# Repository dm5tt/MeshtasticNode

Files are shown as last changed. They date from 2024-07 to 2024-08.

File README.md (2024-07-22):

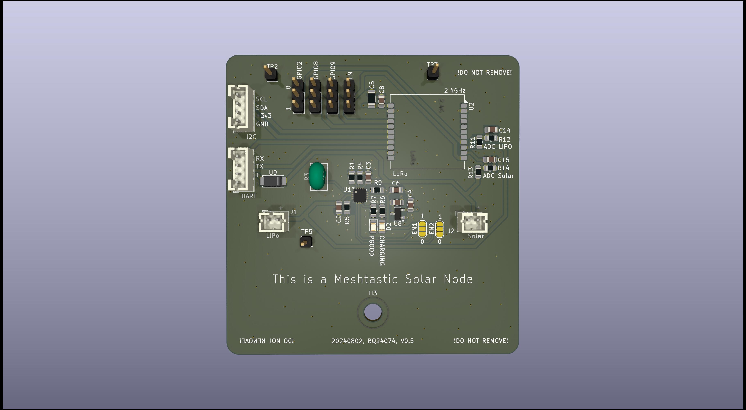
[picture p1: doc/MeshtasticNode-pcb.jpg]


## What is this thing?

This is a Heltec HT-CT62 based Meshtastic Router which can be integrated into a IP68 protected case.

Combined with a solar panel this device can be placed in remote areas to cover a wide range.

For power management a TI BQ24074 is being used which offers pseudo-MPPT and load switching (= battery being deactivated if the sun offers us enough energy to power the device alone).

Voltages can be measured via power divider to GPIO0 (VBUS) or GPIO1 (LiPo)

## Do I have to modify the Software?

No. Only some smaller changes regarding the pin mapping is required.

```
diff --git a/variants/heltec_esp32c3/pins_arduino.h b/variants/heltec_esp32c3/pins_arduino.h
index a717a370..b8ebc09c 100644
--- a/variants/heltec_esp32c3/pins_arduino.h
+++ b/variants/heltec_esp32c3/pins_arduino.h
@@ -6,8 +6,8 @@
 static const uint8_t TX = 21;
 static const uint8_t RX = 20;
 
-static const uint8_t SDA = 1;
-static const uint8_t SCL = 0;
+static const uint8_t SDA = 18;
+static const uint8_t SCL = 19;
 
 static const uint8_t SS = 8;
 static const uint8_t MOSI = 7;
diff --git a/variants/heltec_esp32c3/variant.h b/variants/heltec_esp32c3/variant.h
index 360d9bf1..4f66476d 100644
--- a/variants/heltec_esp32c3/variant.h
+++ b/variants/heltec_esp32c3/variant.h
@@ -1,16 +1,11 @@
-#define BUTTON_PIN 9

-#define LED_PIN 2 // LED
-#define LED_INVERTED 0

 #define HAS_SCREEN 0
 #define HAS_GPS 0
 #undef GPS_RX_PIN
 #undef GPS_TX_PIN
 
+#define BATTERY_PIN 1
+#define ADC_CHANNEL ADC1_GPIO1_CHANNEL
+
 #define USE_SX1262
 #define LORA_SCK 10
 #define LORA_MISO 6
```

### Box

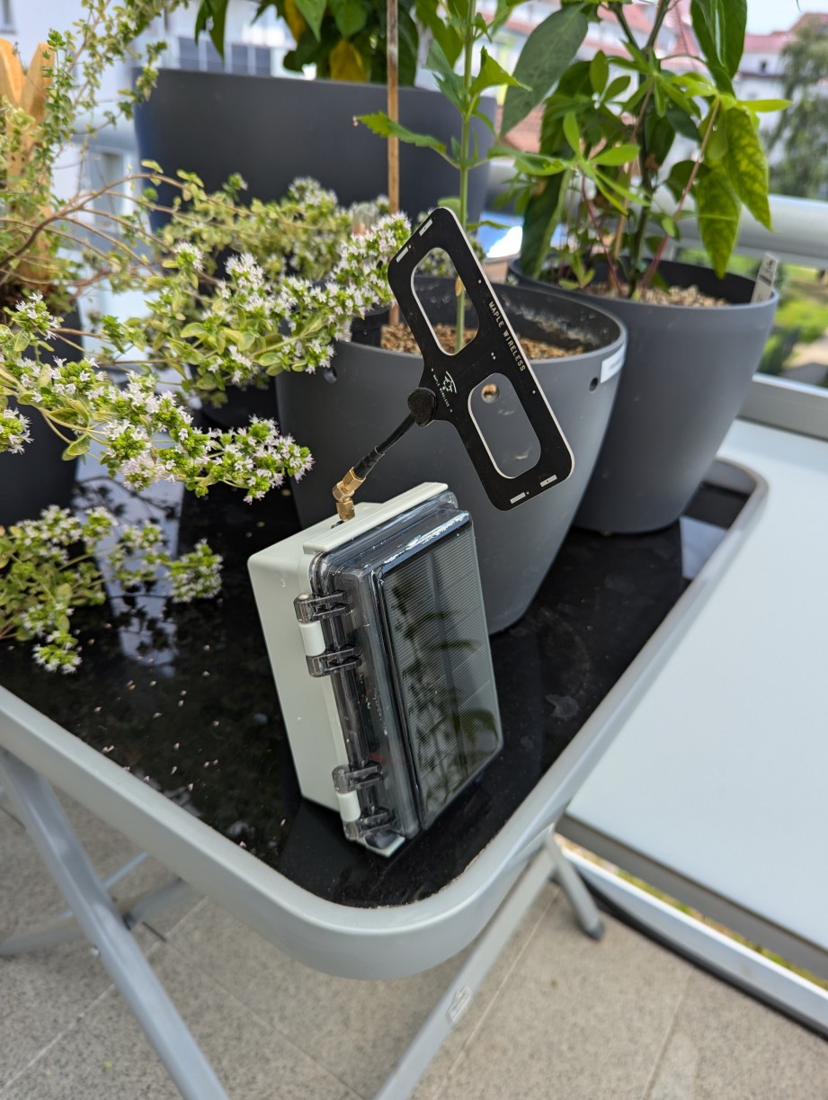
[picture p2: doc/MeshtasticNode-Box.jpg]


### Cabeling

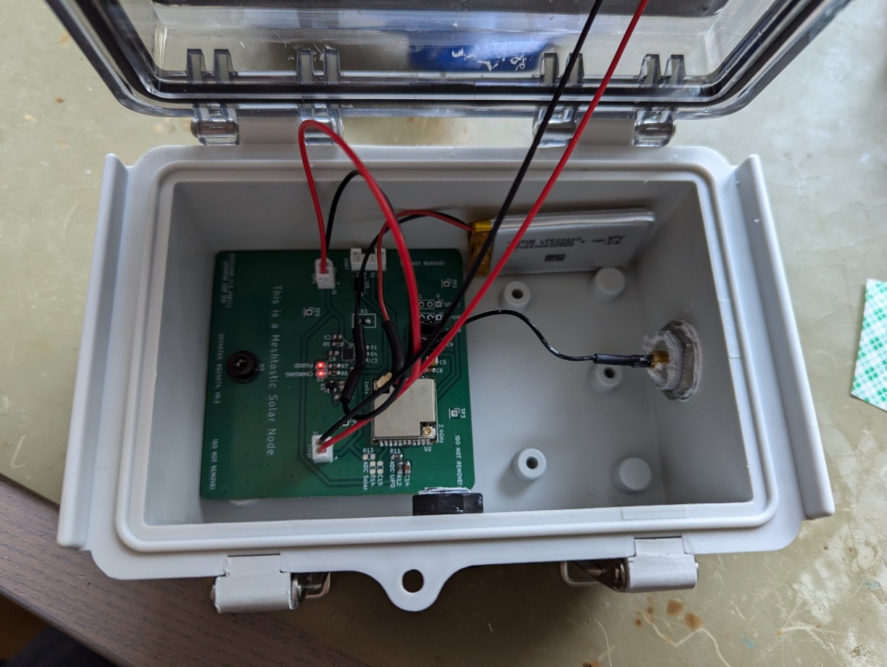
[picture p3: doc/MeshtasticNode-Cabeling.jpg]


### Flashing

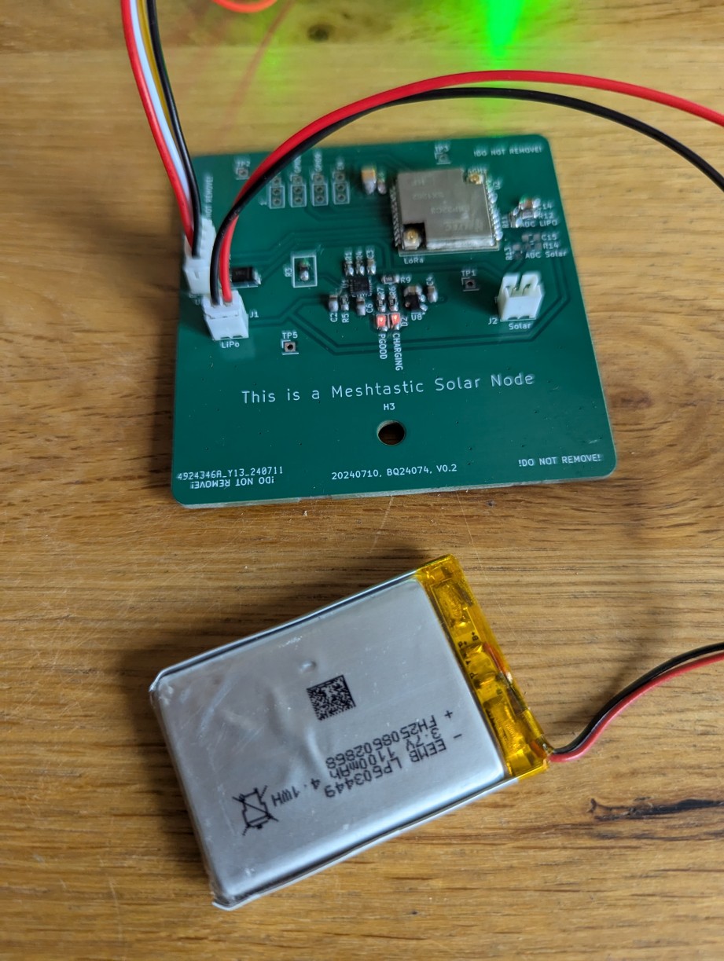
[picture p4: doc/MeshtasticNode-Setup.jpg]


## Lessons learned

Never ever use hot glue even when if the promise that it's UV resistant. It will fail and then the environment will kill all of your electronics.

Professional glue for construction work and water pools/boat seem to survive every kind of weather as long you keep it within its specs.

Using venting plugs with gore tex membrane.

## Future Changes

The solar charging IC will be replaced with    the new TI BQ25308 which will enable us to utilize solar panels from 4.5-17V without burning a single mA into heat.

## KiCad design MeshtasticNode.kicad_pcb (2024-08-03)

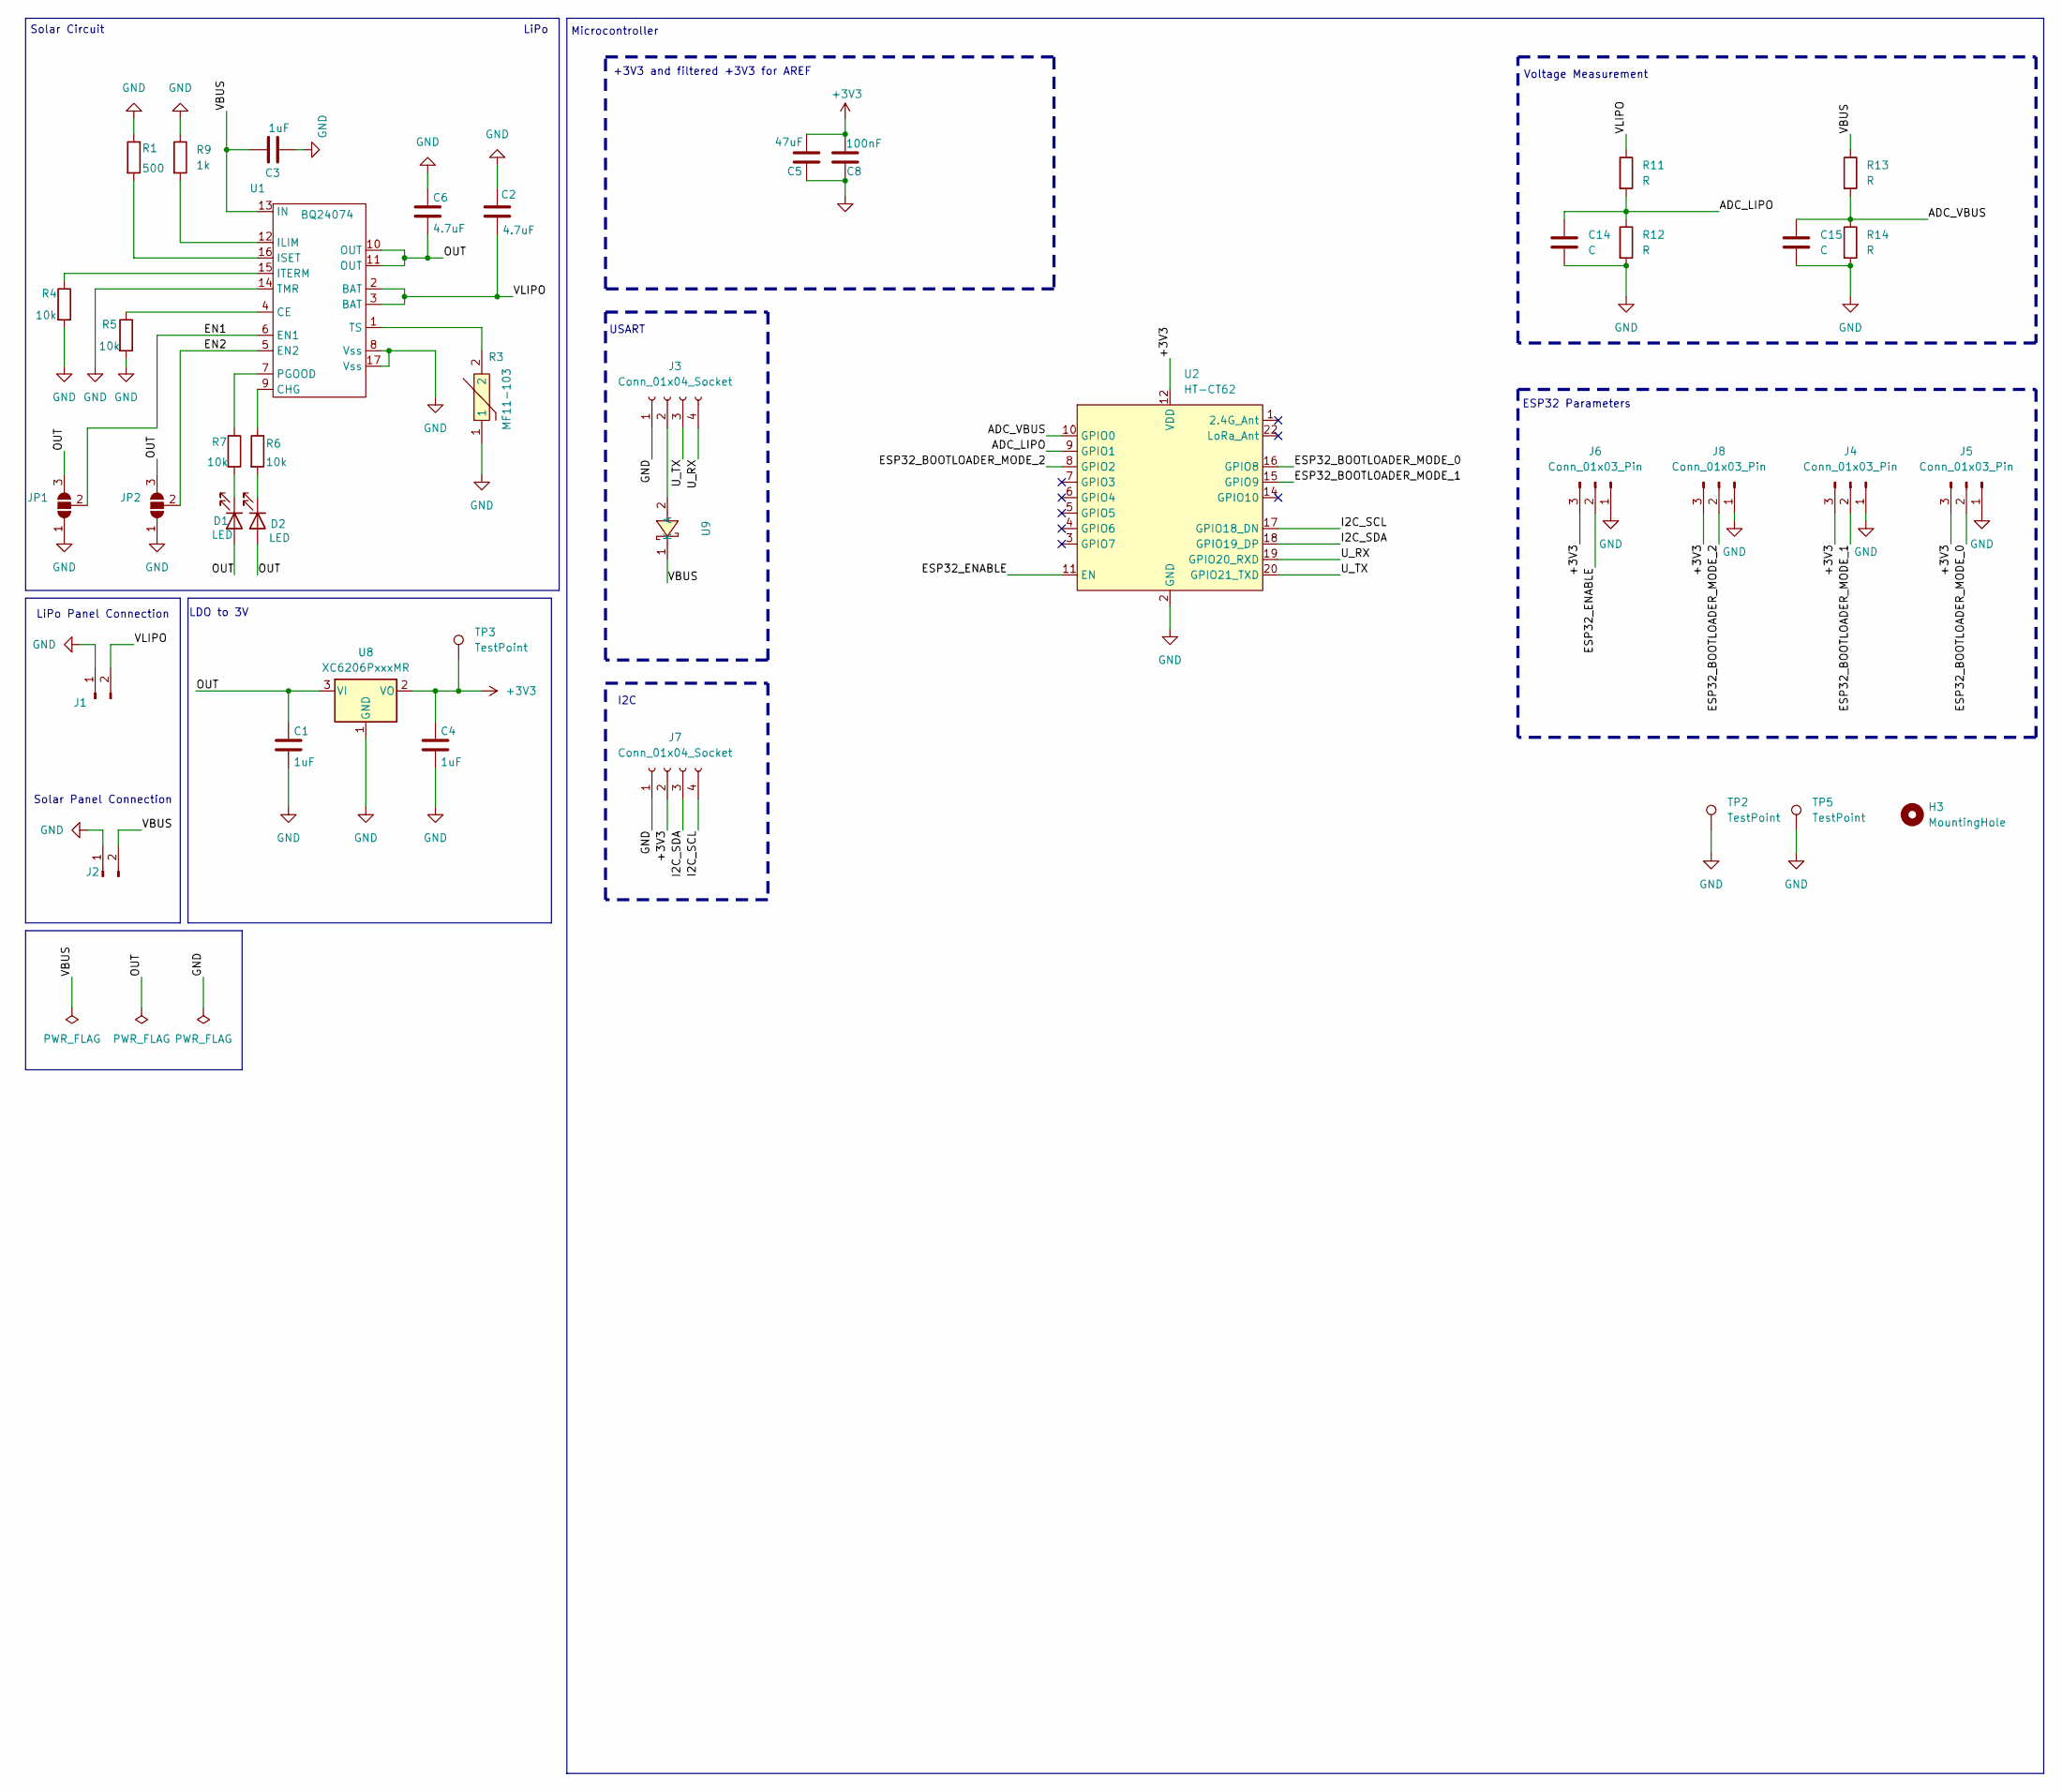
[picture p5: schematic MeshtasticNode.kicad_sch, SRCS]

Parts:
C1, C3, C4: 1uF; C_0805_2012Metric_Pad1.18x1.45mm_HandSolder
C2, C6: 4.7uF; C_0805_2012Metric_Pad1.18x1.45mm_HandSolder
C5: 47uF; R_1206_3216Metric_Pad1.30x1.75mm_HandSolder
C8: 100nF; C_0805_2012Metric_Pad1.18x1.45mm_HandSolder
C14, C15: C; C_0805_2012Metric_Pad1.18x1.45mm_HandSolder
D1, D2: LED; LED_0805_2012Metric_Pad1.15x1.40mm_HandSolder
H3: MountingHole; MountingHole_4.3mm_M4_DIN965
J1, J2: Conn_01x02_Socket; JST_PH_B2B-PH-K_1x02_P2.00mm_Vertical
J3, J7: Conn_01x04_Socket; JST_PH_B4B-PH-K_1x04_P2.00mm_Vertical
J4, J5, J6, J8: Conn_01x03_Pin; PinHeader_1x03_P2.54mm_Vertical
JP1, JP2: SolderJumper_3_Open; SolderJumper-3_P1.3mm_Open_RoundedPad1.0x1.5mm_NumberLabels
R1: 500; R_0805_2012Metric_Pad1.20x1.40mm_HandSolder
R3: MF11-103; RES-TH_L6.5-W4.0-P2.50-D0.5; LCSC Part C70913
R4, R5, R6, R7: 10k; R_0805_2012Metric_Pad1.20x1.40mm_HandSolder
R9: 1k; R_0805_2012Metric_Pad1.20x1.40mm_HandSolder
R11, R12, R13, R14: R; R_0805_2012Metric_Pad1.20x1.40mm_HandSolder
TP2, TP3, TP5: TestPoint; PinHeader_1x01_P2.54mm_Vertical
U1: BQ24074; VQFN-16-1EP_3x3mm_P0.5mm_EP1.68x1.68mm_ThermalVias
U2: HT-CT62; Heltec_HT-CT62
U8: XC6206PxxxMR; SOT-23-3
U9: SS26_C5350986; SMA_L4.3-W2.6-LS5.1-RD; LCSC Part C5350986

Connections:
+3V3: C4.1, C5.2, C8.2, J4.3, J5.3, J6.3, J7.2, J8.3, TP3.1, U2.12 (VDD), U8.2 (VO)
/ADC_LIPO: C14.1, R11.2, R12.1, U2.9 (GPIO1)
/ADC_VBUS: C15.1, R13.2, R14.1, U2.10 (GPIO0)
/EN1: JP1.2 (C), U1.6 (EN1)
/EN2: JP2.2 (C), U1.5 (EN2)
/ESP32_BOOTLOADER_MODE_0: J5.2, U2.16 (GPIO8)
/ESP32_BOOTLOADER_MODE_1: J4.2, U2.15 (GPIO9)
/ESP32_BOOTLOADER_MODE_2: J8.2, U2.8 (GPIO2)
/ESP32_ENABLE: J6.2, U2.11 (EN)
/I2C_SCL: J7.4, U2.17 (GPIO18_DN)
/I2C_SDA: J7.3, U2.18 (GPIO19_DP)
/OUT: C1.1, C6.2, D1.2 (A), D2.2 (A), JP1.3 (B), JP2.3 (B), U1.10 (OUT), U1.11 (OUT), U8.3 (VI)
/U_RX: J3.4, U2.19 (GPIO20_RXD)
/U_TX: J3.3, U2.20 (GPIO21_TXD)
/VBUS: C3.1, J2.2, R13.1, U1.13 (IN), U9.1 (K)
/VLIPO: C2.2, J1.2, R11.1, U1.2 (BAT), U1.3 (BAT)
GND: C1.2, C2.1, C3.2, C4.2, C5.1, C6.1, C8.1, C14.2, C15.2, J1.1, J2.1, J3.1, J4.1, J5.1, J6.1, J7.1, J8.1, JP1.1 (A), JP2.1 (A), R1.1, R3.1, R4.2, R5.2, R9.1, R12.2, R14.2, TP2.1, TP5.1, U1.8 (Vss), U1.14 (TMR), U1.17 (Vss), U2.2 (GND), U2.13 (GND), U2.21 (GND), U8.1 (GND)
unnamed: D1.1 (K), R7.2
unnamed: D2.1 (K), R6.2
unnamed: J3.2, U9.2 (A)
unnamed: R5.1, U1.4 (CE)
unnamed: R6.1, U1.9 (CHG)
unnamed: R9.2, U1.12 (ILIM)
unnamed: R1.2, U1.16 (ISET)
unnamed: R4.1, U1.15 (ITERM)
unnamed: R7.1, U1.7 (PGOOD)
unnamed: R3.2, U1.1 (TS)

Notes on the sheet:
ESP32 Parameters
Solar Circuit
Microcontroller
USART
Voltage Measurement
LiPo
LiPo Panel Connection
+3V3 and filtered +3V3 for AREF
Solar Panel Connection
LDO to 3V
I2C

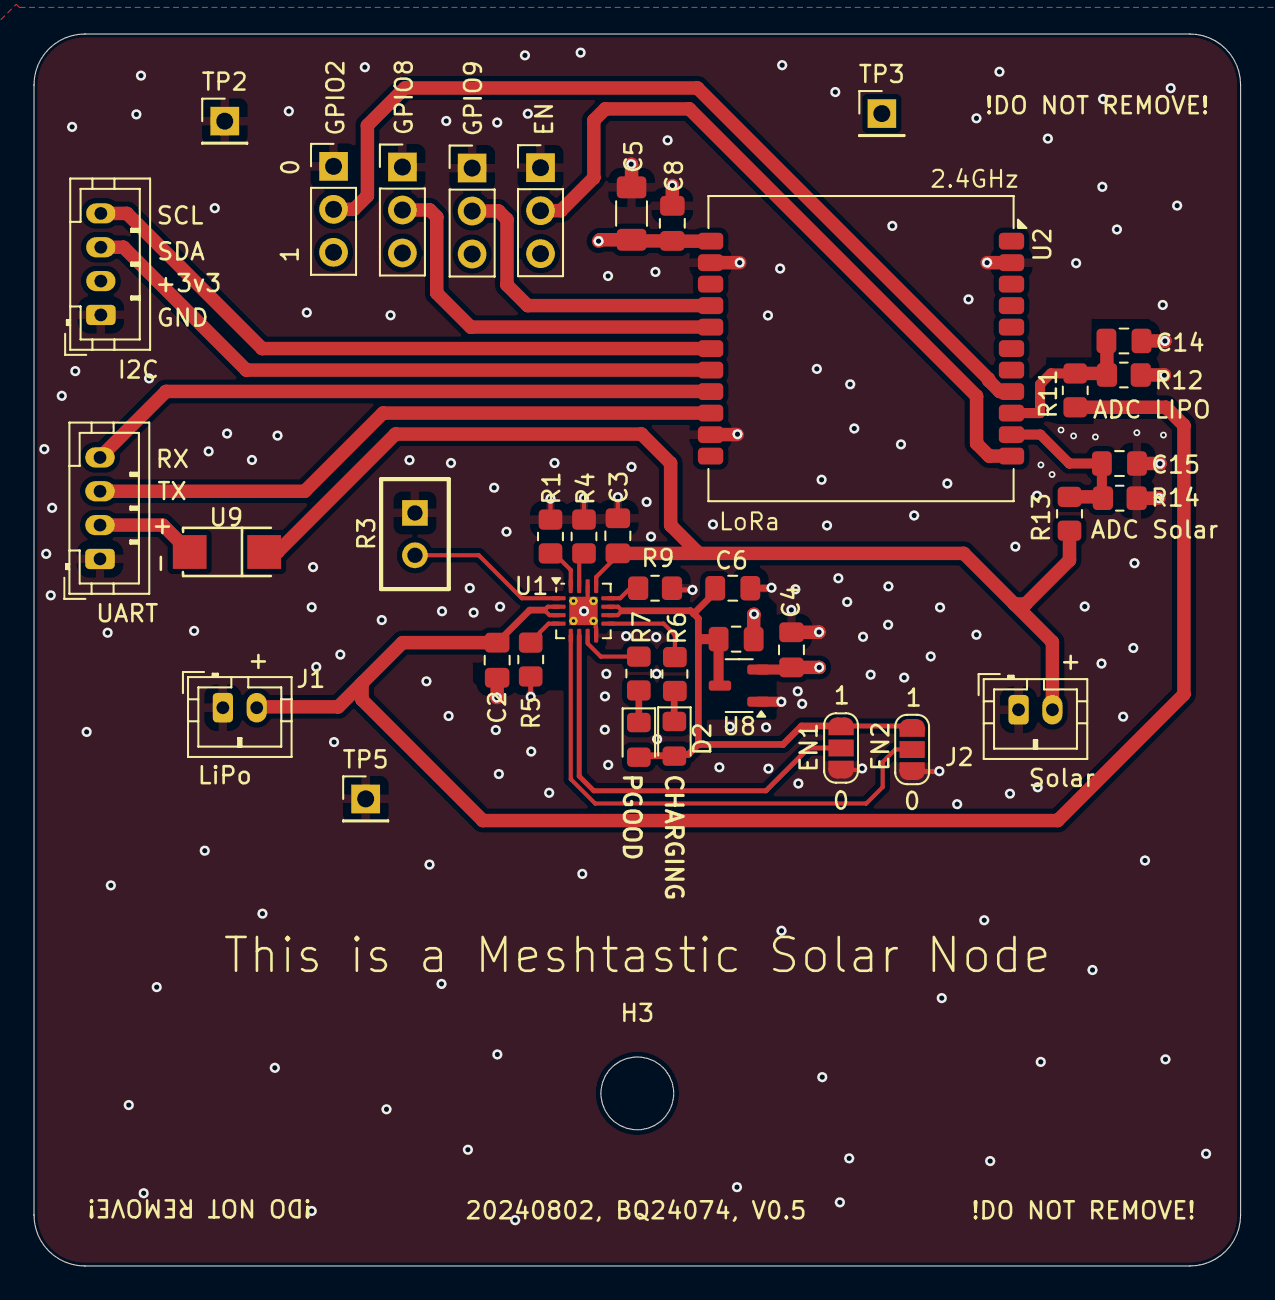
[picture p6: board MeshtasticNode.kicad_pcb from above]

Board: 4 copper layers, 71.3 x 72.8 mm, 40 parts (0 on the bottom side), 27 nets.

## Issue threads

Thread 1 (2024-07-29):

Device is overheating (sun shining through the transparent case) causing the LiPo to stop charging

dm5tt, 2024-07-29:
It looks the the LiPo safety circuit is stopping the device from charging when the sun is directly shining into the case. An attempt to cover  the transparent areas will be the first attempt.

The ESP32 and SX1262 is not affected by this problem as they can work up to 80°C

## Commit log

2024-07-22 pcb: increase maximum current from 500mA to 2A
    [MeshtasticNode.kicad_pcb, MeshtasticNode.kicad_sch]
2024-07-22 pcb: Make EN1 and EN2 selectable. Fixes awful bug.
    [MeshtasticNode.kicad_pcb, MeshtasticNode.kicad_sch]
2024-07-22 pcb: replace picture
2024-07-22 pcb: prepare for v0.3
    [MeshtasticNode.kicad_pcb]
2024-07-22 pcb: remove 90° ankle
    [MeshtasticNode.kicad_pcb]
2024-07-22 pcb: add I2C port and remove a few warnings from EN1/EN2 solder switches
    [MeshtasticNode.kicad_pcb, MeshtasticNode.kicad_sch]
2024-08-02 pcb: add lost front and back groundplane, use thermal via footprint for BQ24074
    [MeshtasticNode.kicad_pcb, MeshtasticNode.kicad_sch]
2024-08-03 pcb: smaller non-functional cleanups of the design
    [MeshtasticNode.kicad_pcb]
2024-08-03 pcb: smaller non-functional cleanups
    [MeshtasticNode.kicad_pcb]
